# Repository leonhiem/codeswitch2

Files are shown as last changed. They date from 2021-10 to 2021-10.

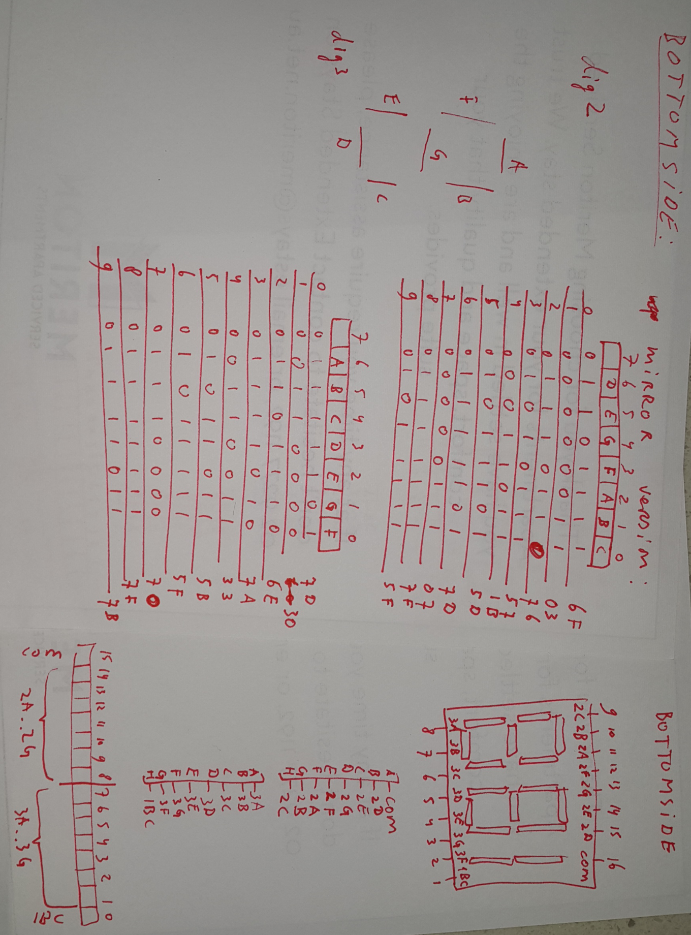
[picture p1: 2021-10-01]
firmware/doc/lcd_bottomside.png

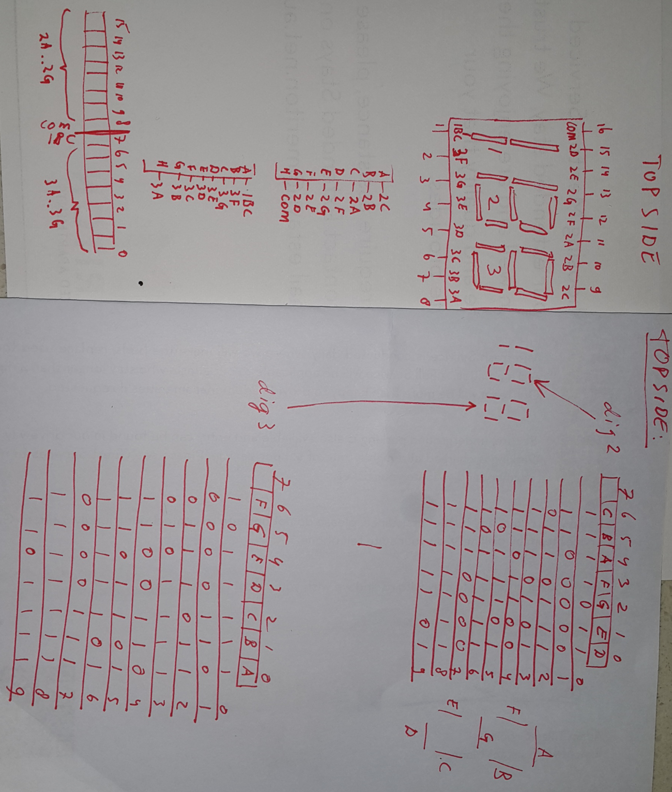
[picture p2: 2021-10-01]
firmware/doc/lcd_topside.png

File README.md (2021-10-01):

# codeswitch2
Codeswitch 2nd edition. To open/close a relay

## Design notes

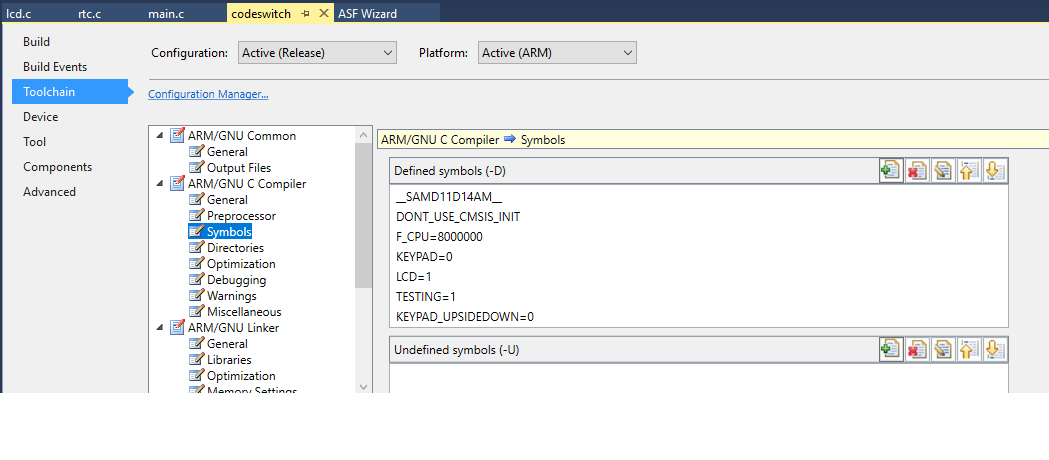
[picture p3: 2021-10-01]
firmware/codeswitch2/samd11/compiler.png

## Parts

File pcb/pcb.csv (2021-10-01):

Reference | Quantity | Value | Footprint | Datasheet | Mfg_code | BOM
C1 C11 | 2 | 10u/25V | capacitor:C_0805_reflow |  | TMK212BBJ106KG-T
C10 C2 C6 C7 C8 C9 | 6 | 100n | capacitor:C_0805_reflow |  | C0805C104K5RACTU
C12 C13 C3 | 3 | 4u7/25V | capacitor:C_0805_reflow |  | CL21A475KAQNNNG
C4 C5 | 2 | 15pF | capacitor:C_0805_reflow |  | CL21C150JBANNNC
D1 D3 | 2 | 1N4148 | Diodes:SOD-80A |  | LL4148
D2 | 1 | S1DB | Diodes_SMD:D_SMB_Handsoldering |  | S1DB-13-F
F2 | 1 | Polyfuse 1.1A-hold 2.2A-trip | Resistors_SMD:R_1812 |  | 0ZCG0110BF2B
J1 | 1 | AUX Ctrl | Pin_Headers:Pin_Header_Straight_1x06_Pitch2.54mm
LCD1 | 1 | LUMEX_LCD_S2X1C50TR | lcd:LUMEX_LCD_S2X1C50TR |  | LCD-S2X1C50TR
LS1 | 1 | piezo | buzzer:MagneticBuzzer_StarMicronics_HMB-06_HMB-12 |  | PT-1340P-PQ
P1 | 1 | serial | Pin_Headers:Pin_Header_Straight_1x04_Pitch2.54mm |  | PRPC004SBAN-M71RC
P3 | 1 | Atmel-ICE | myconnectors:Atmel_ICE |  | 3220-10-0100-00
P2 P4 P5 P6 P7 P9 | 6 | (faston male 6.35mm) | myconnectors:faston_m_63 | http://www.digikey.nl/product-detail/en/te-connectivity-amp-connectors/1217861-1/A100452TR-ND/1148769 | 1217861-1
Q10 Q2 Q5 | 3 | MMBT3906 | TO_SOT_Packages_SMD:SOT-23 |  | MMBT3906LT3G
Q1 Q11 Q12 Q13 Q3 Q4 Q6 Q8 Q9 | 9 | MMBT3904 | TO_SOT_Packages_SMD:SOT-23 |  | MMBT3904LT3G
Q7 | 1 | PSMN7R5-60YLX | TO_SOT_Packages_SMD:TDSON-8-1_HandSoldering |  | PSMN7R5-60YLX
R15 R16 R30 R33 R35 R6 | 6 | 4k7 | resistor:R_0805_reflow |  | RMCF0805FT4K70
R13 R14 R17 R22 R24 R26 R37 R4 R7 | 9 | 100k | resistor:R_0805_reflow |  | RMCF0805FT100K
R1 R11 R19 R2 R25 R29 R38 | 7 | 150 | resistor:R_0805_reflow |  | RMCF0805FT150R
R28 | 1 | 3k | resistor:R_0805_reflow |  | RMCF0805FT3K00
R10 R12 R18 R23 R27 R3 R31 R32 R36 R8 R9 | 11 | 10k | resistor:R_0805_reflow |  | RMCF0805FT10K0
R34 | 1 | 1M | resistor:R_0805_reflow |  | RMCF0805JT1M00
R20 R21 R5 | 3 | 1k | resistor:R_0805_reflow |  | RMCF0805FT1K00
SW1 SW10 SW11 SW12 SW2 SW3 SW4 SW5 SW6 SW7 SW8 SW9 | 12 | button | myconnectors:SW_SPST_keypad
TP1 TP3 TP5 TP6 TP7 TP8 | 6 | TP | Pin_Headers:Pin_Header_Straight_1x01_Pitch2.54mm
TP9 | 1 | GND | Pin_Headers:Pin_Header_Straight_1x01_Pitch2.54mm
U2 | 1 | LM358 | Housings_SOIC:SOIC-8_3.9x4.9mm_Pitch1.27mm |  | LM358ADT
U3 | 1 | ATSAMD11D14A-M | Housings_DFN_QFN:QFN-24-1EP_4x4mm_Pitch0.5mm | http://www.atmel.com/Images/Atmel-42363-SAM-D11_Datasheet.pdf | ATSAMD11D14A-MUT | MCU ATMEL ATSAMD11D14A-M
U4 U5 | 2 | 74HC595 | Housings_SOIC:SOIC-16_3.9x9.9mm_Pitch1.27mm |  | MM74HC595M
U1 U6 | 2 | HT7533 | TO_SOT_Packages_SMD:SOT-89-3_Handsoldering
Y1 | 1 | 32.768kHz | xtal:Crystal_SMD_Abracon_4pin_32768khz |  | ABS25-32.768KHZ-T
ZD1 | 1 | ESDA6V1W5 | TO_SOT_Packages_SMD:SOT-353_SC-70-5_Handsoldering |  | ESDA6V1W5

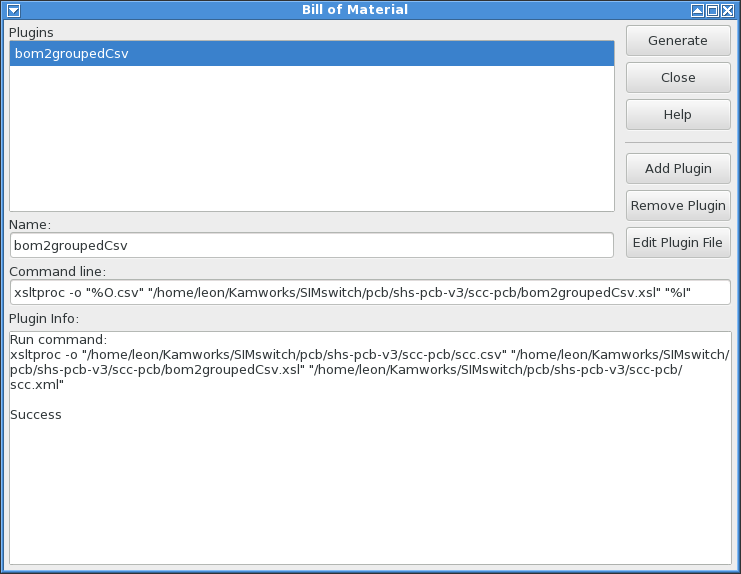
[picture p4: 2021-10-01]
pcb/howto_bom.png

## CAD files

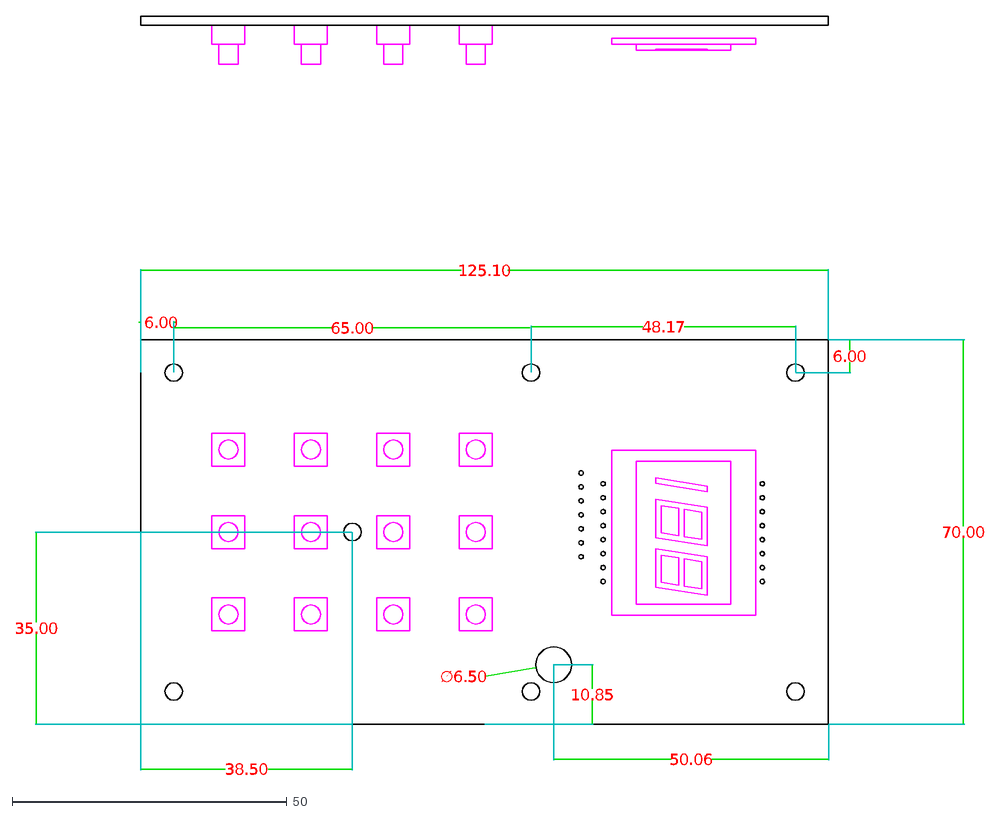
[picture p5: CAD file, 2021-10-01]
pcb/part1-2-NEW.dxf
70.00
125.10
6.00
65.00
48.17
38.50
35.00
10.85
50.06
∅6.50

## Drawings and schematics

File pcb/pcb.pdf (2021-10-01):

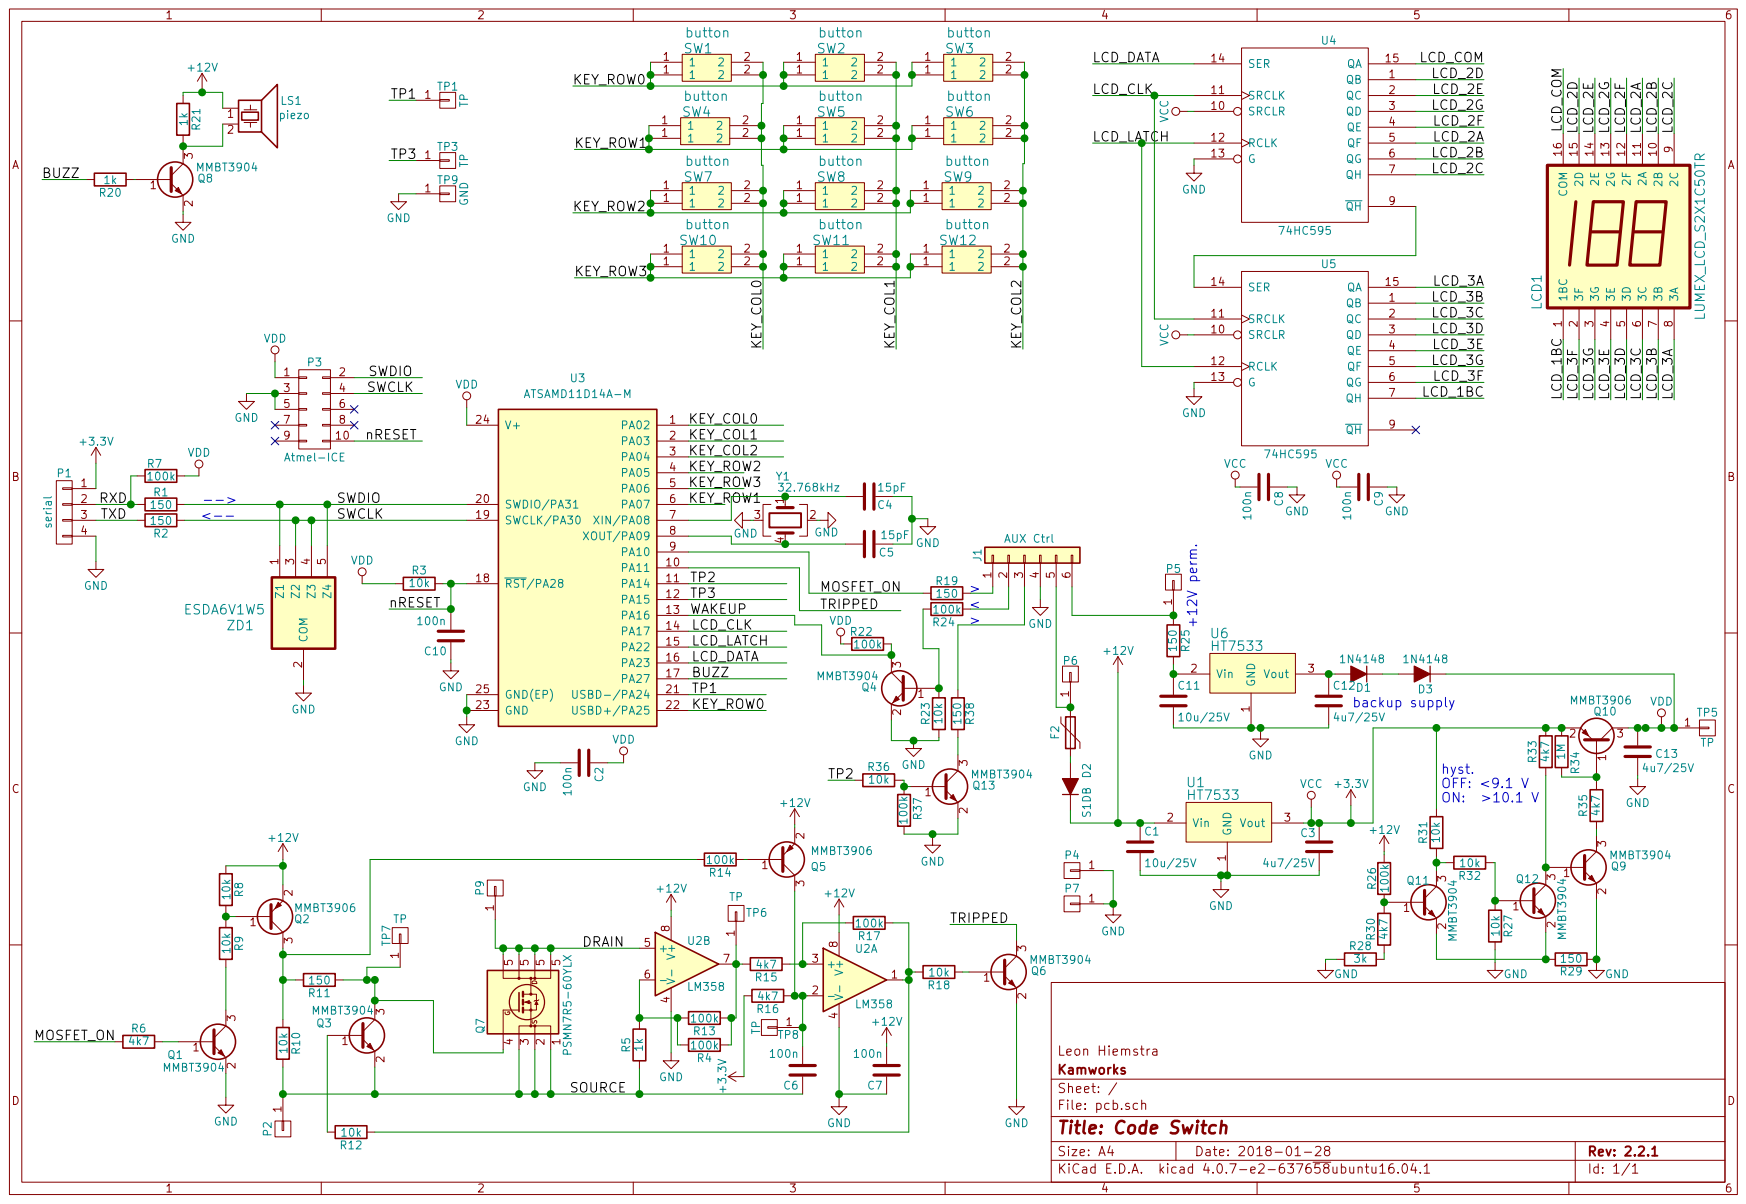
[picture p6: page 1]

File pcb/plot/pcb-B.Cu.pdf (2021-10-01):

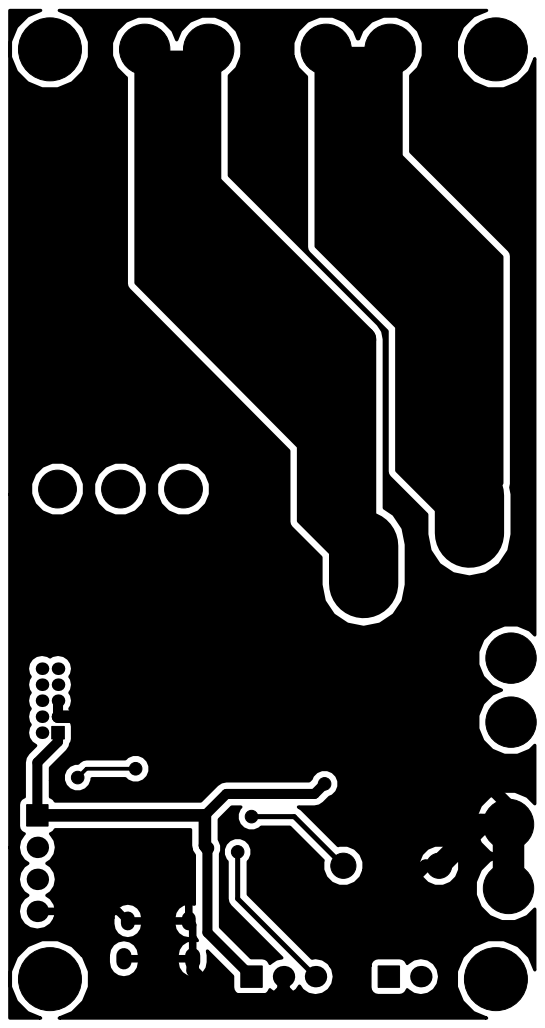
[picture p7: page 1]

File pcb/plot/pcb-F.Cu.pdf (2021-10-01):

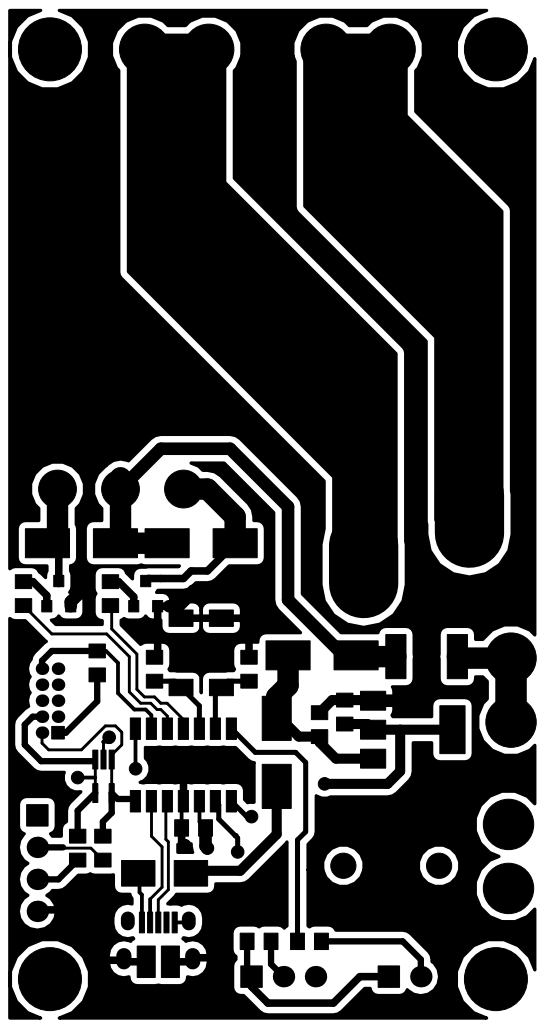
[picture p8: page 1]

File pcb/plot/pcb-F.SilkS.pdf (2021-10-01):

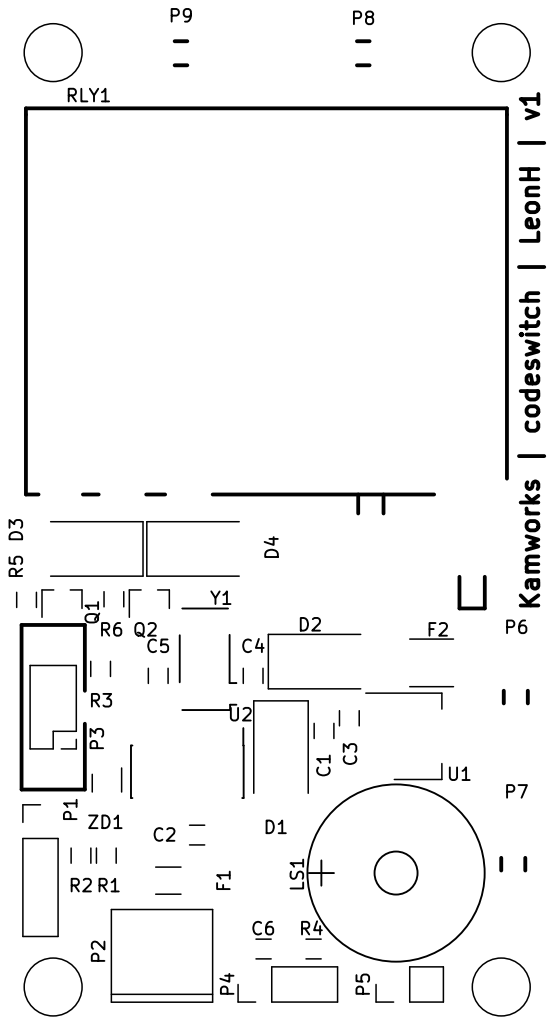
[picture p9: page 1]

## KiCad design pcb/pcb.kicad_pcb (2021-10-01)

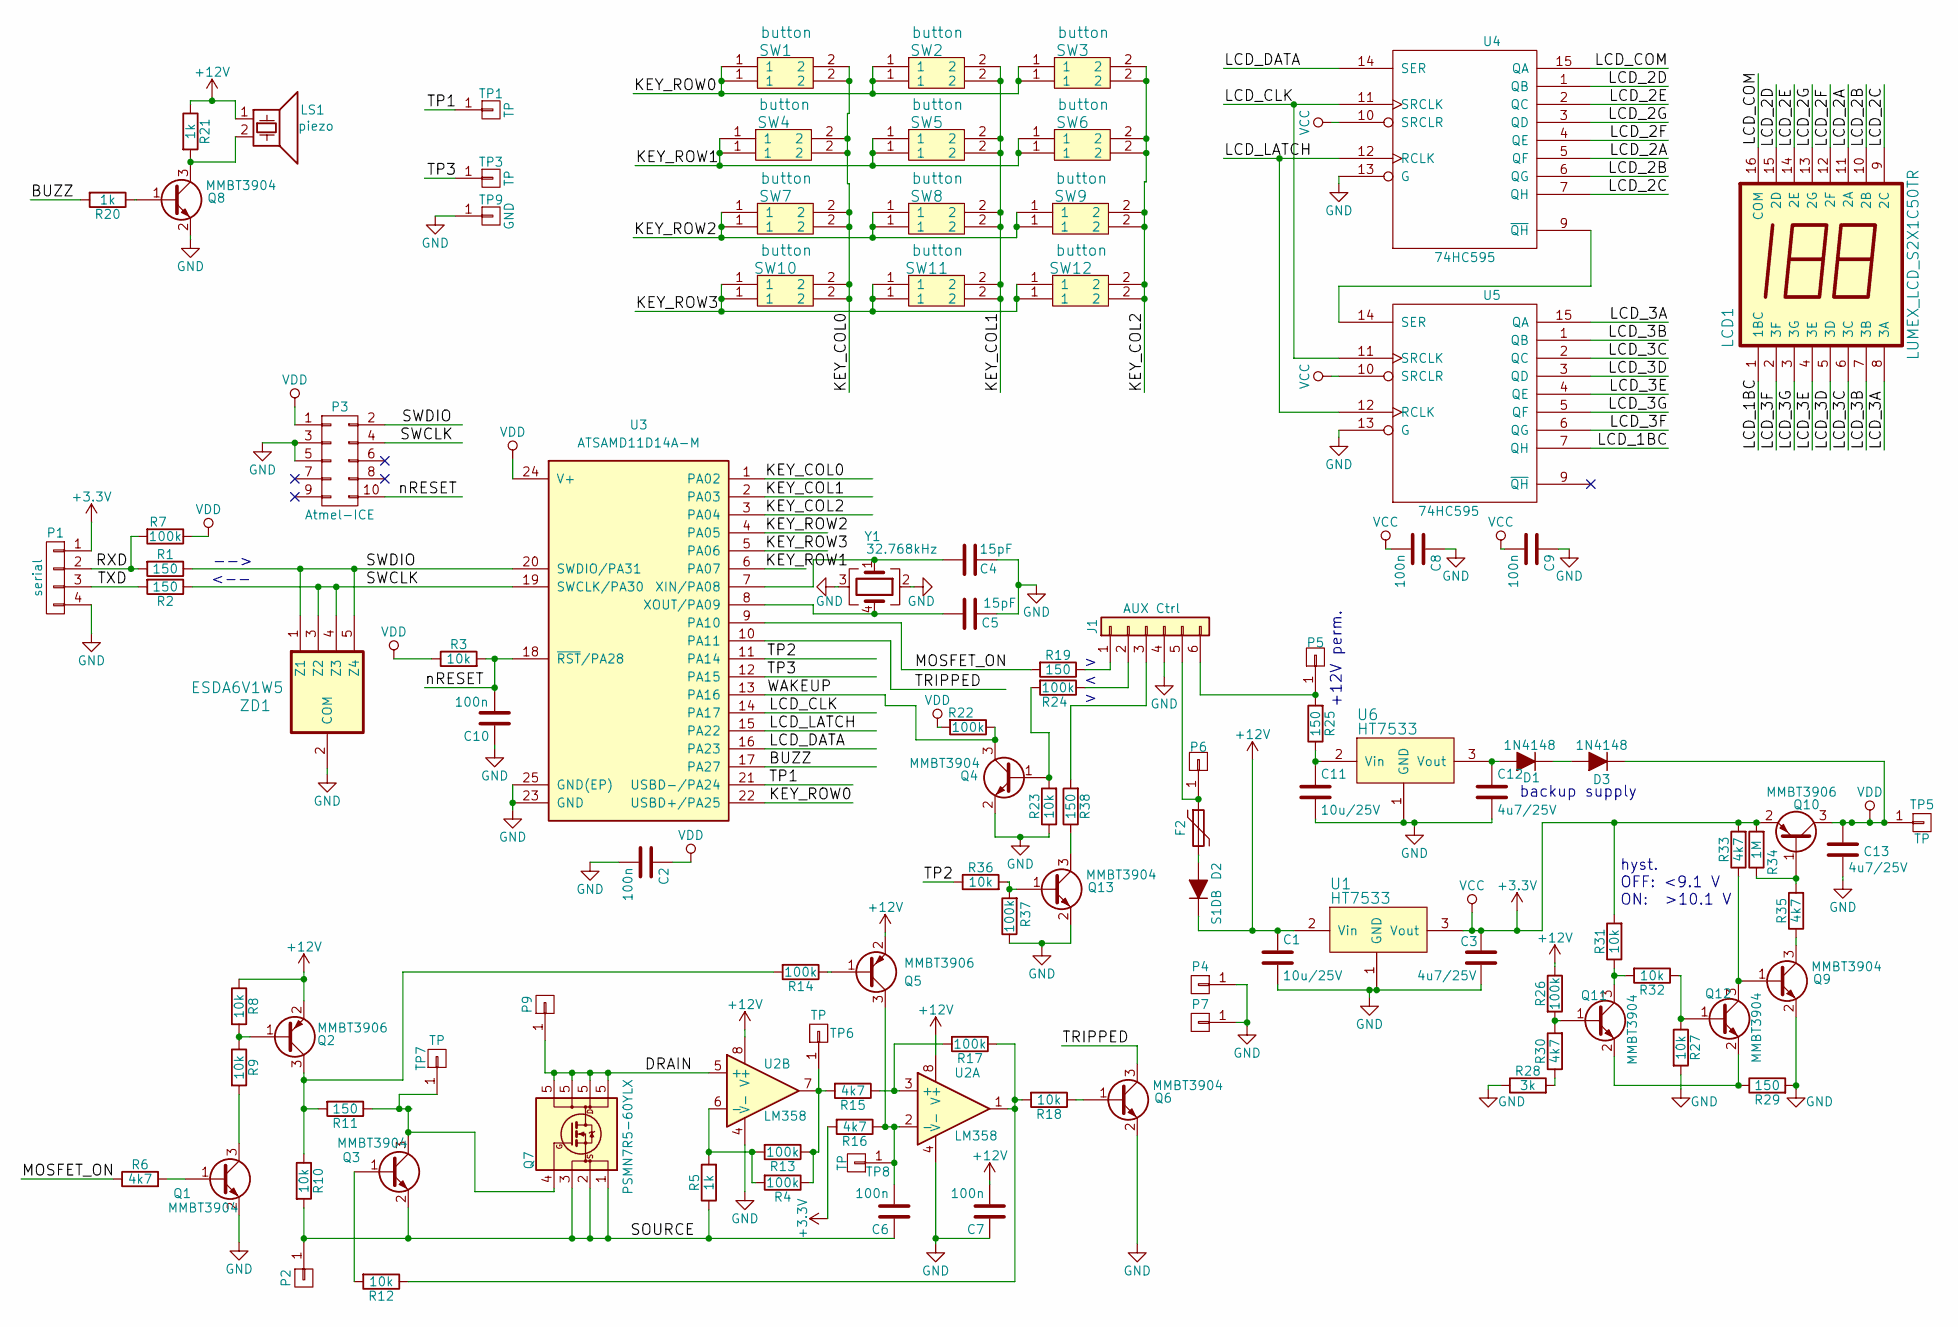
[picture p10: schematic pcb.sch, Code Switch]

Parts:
C1, C11: 10u/25V; C_0805_reflow
C2, C6, C7, C8, C9, C10: 100n; C_0805_reflow
C3, C12, C13: 4u7/25V; C_0805_reflow
C4, C5: 15pF; C_0805_reflow
D1, D3: 1N4148; SOD-80A
D2: S1DB; D_SMB_Handsoldering
F2: Polyfuse 1.1A-hold 2.2A-trip; R_1812
J1: AUX Ctrl; Pin_Header_Straight_1x06_Pitch2.54mm
LCD1: LUMEX_LCD_S2X1C50TR
LS1: piezo; MagneticBuzzer_StarMicronics_HMB-06_HMB-12
P1: serial; Pin_Header_Straight_1x04_Pitch2.54mm
P2, P4, P5, P6, P7, P9: (faston male 6.35mm); faston_m_63
P3: Atmel-ICE; Atmel_ICE
Q1, Q3, Q4, Q6, Q8, Q9, Q11, Q12, Q13: MMBT3904; SOT-23
Q2, Q5, Q10: MMBT3906; SOT-23
Q7: PSMN7R5-60YLX; TDSON-8-1_HandSoldering
R1, R2, R11, R19, R25, R29, R38: 150; R_0805_reflow
R3, R8, R9, R10, R12, R18, R23, R27, R31, R32, R36: 10k; R_0805_reflow
R4, R7, R13, R14, R17, R22, R24, R26, R37: 100k; R_0805_reflow
R5, R20, R21: 1k; R_0805_reflow
R6, R15, R16, R30, R33, R35: 4k7; R_0805_reflow
R28: 3k; R_0805_reflow
R34: 1M; R_0805_reflow
SW1, SW2, SW3, SW4, SW5, SW6, SW7, SW8, SW9, SW10, SW11, SW12: button; SW_SPST_keypad
TP1, TP3, TP5, TP6, TP7, TP8: TP; Pin_Header_Straight_1x01_Pitch2.54mm
TP9: GND; Pin_Header_Straight_1x01_Pitch2.54mm
U1, U6: HT7533; SOT-89-3_Handsoldering
U2: LM358; SOIC-8_3.9x4.9mm_Pitch1.27mm
U3: ATSAMD11D14A-M; QFN-24-1EP_4x4mm_Pitch0.5mm
U4, U5: 74HC595; SOIC-16_3.9x9.9mm_Pitch1.27mm
Y1: 32.768kHz; Crystal_SMD_Abracon_4pin_32768khz
ZD1: ESDA6V1W5; SOT-353_SC-70-5_Handsoldering

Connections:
+3V3: C3.1, C8.2, C9.2, P1.1, Q10.2 (E), R16.2, R31.2, R33.2, R34.2, U1.3 (Vout), U4.10 (SRCLR), U4.16 (VCC), U5.10 (SRCLR), U5.16 (VCC)
+12V: C1.1, C7.2, D2.1 (K), LS1.1, Q2.2 (E), Q5.2 (E), R8.1, R21.1, R26.1, U1.2 (Vin), U2.8 (V+)
/BUZZ: R20.2, U3.17 (PA27)
/DRAIN: P9.1, Q7.5 (D), U2.5 (+)
/KEY_COL0: SW1.2, SW4.2, SW7.2, SW10.2, U3.1 (PA02)
/KEY_COL1: SW2.2, SW5.2, SW8.2, SW11.2, U3.2 (PA03)
/KEY_COL2: SW3.2, SW6.2, SW9.2, SW12.2, U3.3 (PA04)
/KEY_ROW0: SW1.1, SW2.1, SW3.1, U3.22 (USBD+/PA25)
/KEY_ROW1: SW4.1, SW5.1, SW6.1, U3.6 (PA07)
/KEY_ROW2: SW7.1, SW8.1, SW9.1, U3.4 (PA05)
/KEY_ROW3: SW10.1, SW11.1, SW12.1, U3.5 (PA06)
/LCD_1BC: LCD1.1 (1BC), U5.7 (QH)
/LCD_2A: LCD1.11 (2A), U4.5 (QF)
/LCD_2B: LCD1.10 (2B), U4.6 (QG)
/LCD_2C: LCD1.9 (2C), U4.7 (QH)
/LCD_2D: LCD1.15 (2D), U4.1 (QB)
/LCD_2E: LCD1.14 (2E), U4.2 (QC)
/LCD_2F: LCD1.12 (2F), U4.4 (QE)
/LCD_2G: LCD1.13 (2G), U4.3 (QD)
/LCD_3A: LCD1.8 (3A), U5.15 (QA)
/LCD_3B: LCD1.7 (3B), U5.1 (QB)
/LCD_3C: LCD1.6 (3C), U5.2 (QC)
/LCD_3D: LCD1.5 (3D), U5.3 (QD)
/LCD_3E: LCD1.4 (3E), U5.4 (QE)
/LCD_3F: LCD1.2 (3F), U5.6 (QG)
/LCD_3G: LCD1.3 (3G), U5.5 (QF)
/LCD_CLK: U3.14 (PA17), U4.11 (SRCLK), U5.11 (SRCLK)
/LCD_COM: LCD1.16 (COM), U4.15 (QA)
/LCD_DATA: U3.16 (PA23), U4.14 (SER)
/LCD_LATCH: U3.15 (PA22), U4.12 (RCLK), U5.12 (RCLK)
/MOSFET_ON: R6.1, R19.2, U3.9 (PA10)
/RXD: P1.2, R1.2, R7.2
/SOURCE: C6.1, P2.1, Q3.2 (E), Q7.1 (S), Q7.2 (S), Q7.3 (S), R5.1, R10.2
/SWCLK: P3.4, R2.1, U3.19 (SWCLK/PA30), ZD1.3 (Z2), ZD1.4 (Z3)
/SWDIO: P3.2, R1.1, U3.20 (SWDIO/PA31), ZD1.1 (Z1), ZD1.5 (Z4)
/TP1: TP1.1, U3.21 (USBD-/PA24)
/TP2: R36.1, U3.11 (PA14)
/TP3: TP3.1, U3.12 (PA15)
/TRIPPED: Q6.3 (C), U3.10 (PA11)
/TXD: P1.3, R2.2
/WAKEUP: Q4.3 (C), R22.1, U3.13 (PA16)
/nRESET: C10.2, P3.10, R3.2, U3.18 (~RST~/PA28)
GND: C1.2, C2.2, C3.2, C4.1, C5.1, C7.1, C8.1, C9.1, C10.1, C11.2, C12.2, C13.2, J1.4, P1.4, P3.3, P3.5, P4.1, P7.1, Q1.2 (E), Q4.2 (E), Q6.2 (E), Q8.2 (E), Q9.2 (E), Q13.2 (E), R23.1, R27.2, R28.1, R29.2, R37.1, TP9.1, U1.1 (GND), U2.4 (V-), U3.23 (GND), U3.25 (GND(EP)), U4.8 (GND), U4.13 (G), U5.8 (GND), U5.13 (G), U6.1 (GND), Y1.2, Y1.3, ZD1.2 (COM)
unnamed: C4.2, U3.7 (XIN/PA08), Y1.1
unnamed: C5.2, U3.8 (XOUT/PA09), Y1.4
unnamed: C6.2, Q5.3 (C), R16.1, TP8.1, U2.2 (-)
unnamed: C11.1, R25.1, U6.2 (Vin)
unnamed: C12.1, D1.2 (A), U6.3 (Vout)
unnamed: D1.1 (K), D3.2 (A)
unnamed: D2.2 (A), F2.2
unnamed: F2.1, J1.5, P6.1
unnamed: J1.1, R19.1
unnamed: J1.2, R24.1
unnamed: J1.3, R38.2
unnamed: J1.6, P5.1, R25.2
unnamed: LS1.2, Q8.3 (C), R21.2
unnamed: Q1.1 (B), R6.2
unnamed: Q1.3 (C), R9.2
unnamed: Q2.1 (B), R8.2, R9.1
unnamed: Q2.3 (C), R10.1, R11.2, R14.2
unnamed: Q3.1 (B), R12.2
unnamed: Q3.3 (C), Q7.4 (G), R11.1, TP7.1
unnamed: Q4.1 (B), R23.2, R24.2
unnamed: Q5.1 (B), R14.1
unnamed: Q6.1 (B), R18.1
unnamed: Q8.1 (B), R20.1
unnamed: Q9.3 (C), R35.1
unnamed: Q10.1 (B), R34.1, R35.2
unnamed: Q11.1 (B), R26.2, R30.2
unnamed: Q11.2 (E), Q12.2 (E), R29.1
unnamed: Q11.3 (C), R31.1, R32.2
unnamed: Q12.1 (B), R27.1, R32.1
unnamed: Q9.1 (B), Q12.3 (C), R33.1
unnamed: Q13.1 (B), R36.2, R37.2
unnamed: Q13.3 (C), R38.1
unnamed: R12.1, R17.1, R18.2, U2.1
unnamed: R4.1, R13.1, R15.2, TP6.1, U2.7
unnamed: R4.2, R5.2, R13.2, U2.6 (-)
unnamed: R15.1, R17.2, U2.3 (+)
unnamed: R28.2, R30.1
unnamed: U4.9 (~QH), U5.14 (SER)
VDD: C2.1, C13.1, D3.1 (K), P3.1, Q10.3 (C), R3.1, R7.1, R22.2, TP5.1, U3.24 (V+)

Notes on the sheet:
-->
<--
backup supply
+12V perm.
hyst. OFF: <9.1 V ON: >10.1 V

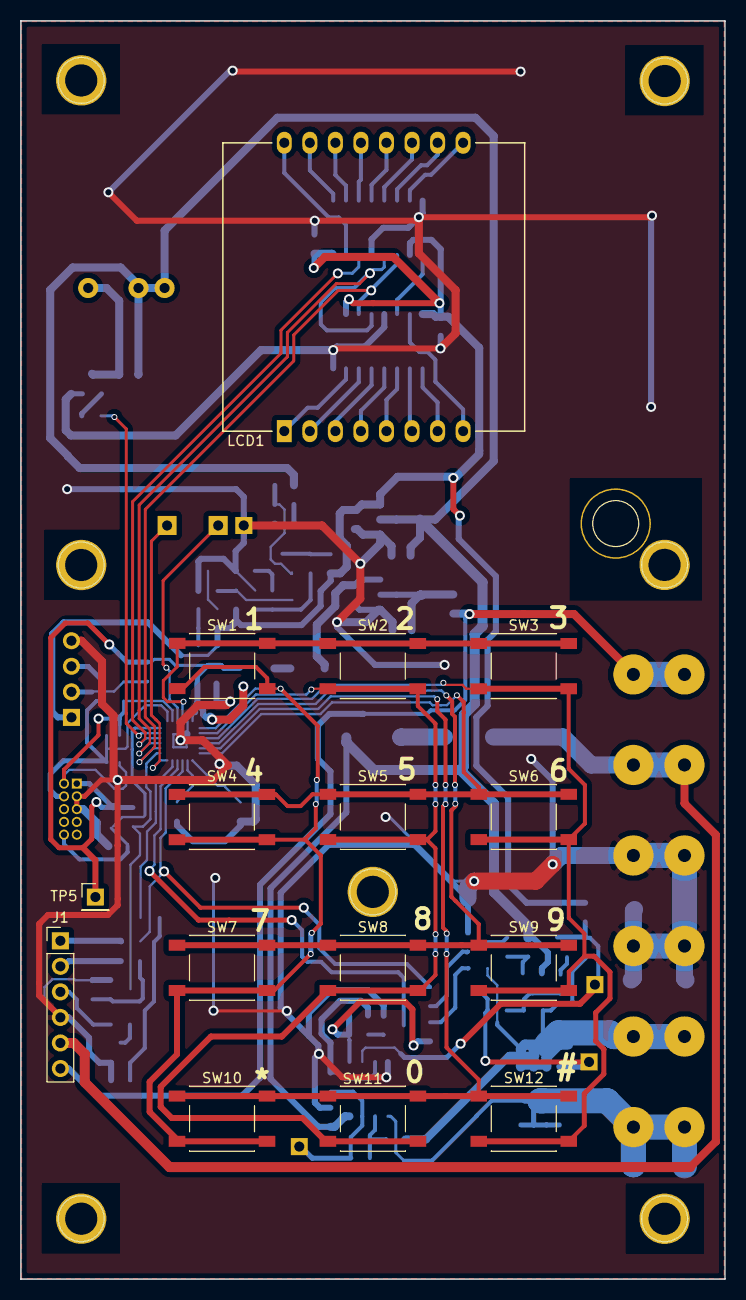
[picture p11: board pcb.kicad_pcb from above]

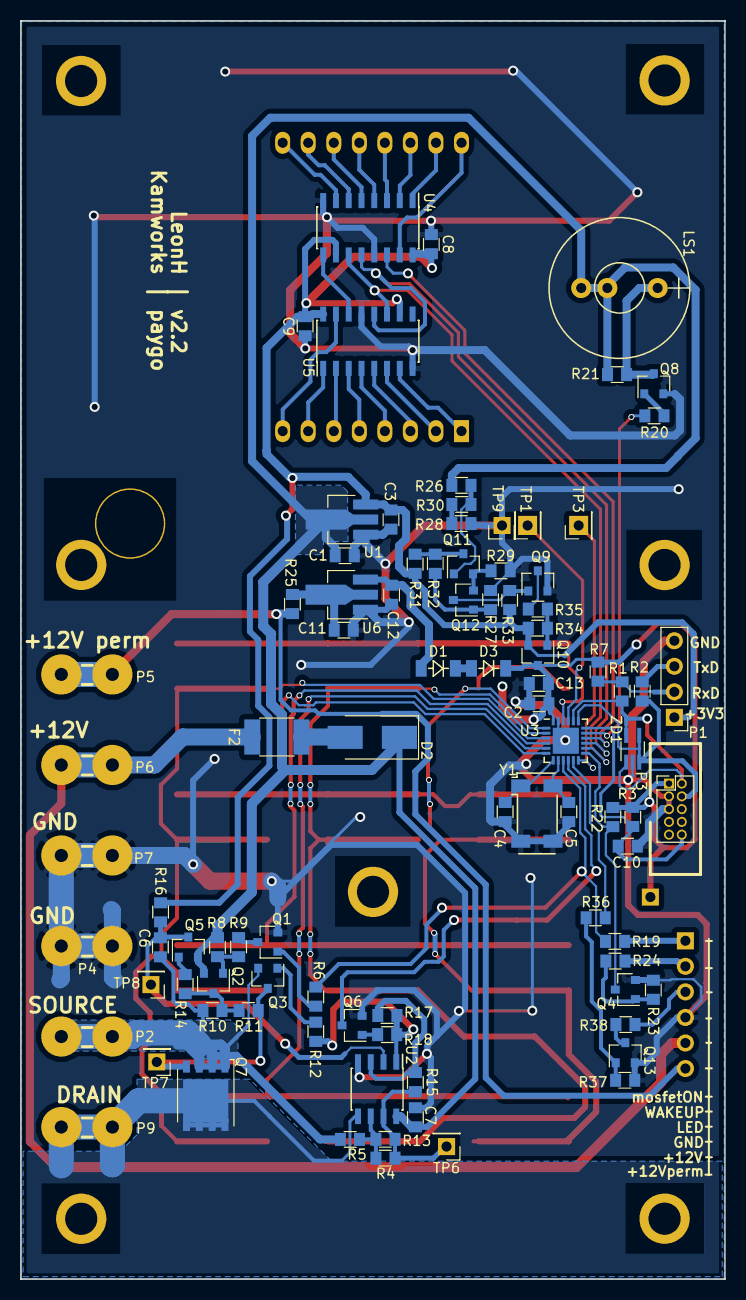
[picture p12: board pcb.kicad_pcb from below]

Board: 2 copper layers, 70.0 x 125.1 mm, 106 parts (91 on the bottom side), 82 nets.

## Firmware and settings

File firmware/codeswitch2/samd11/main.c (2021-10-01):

/*
 * Kamworks Codeswitch2 firmware
 *
 * Author: Leon Hiemstra <l.hiemstra@gmail.com>
 *
 * Compiler tool: Atmel Studio 7.0.1417
 *
 * Microcontroller: ATSAMD11D14AM
 * Required fuse settings: none (keep default)
 *
 * (Arduino IR decoder derived from: ...)
 */

//-----------------------------------------------------------------------------
#include <stdlib.h>
#include <stdio.h>
#include <stdint.h>
#include <stdbool.h>
#include <string.h>
#include "samd11.h"
#include "hal_gpio.h"
#include "utils.h"
#include "rtc.h"
#include "tone.h"
#include "flash.h"
#include "keypad.h"
#include "lcd.h"
#include "wdt.h"


#define VERSION     2
#define SUBVERSION  15


#ifndef KEYPAD_INTEGRATED
#  define KEYPAD_INTEGRATED 1 // enabled
#endif

#ifndef TESTING
#  define TESTING 0 // disabled
#endif

#ifndef LCD
#  define LCD 0  // top (0=bottom)
#endif

volatile bool alarmTriggered = false;

volatile bool usart_rx_ready=false;
volatile bool usart_tx_ready=true;
volatile bool print_info=false;
volatile uint8_t bod33_tripped,wdt_wakeup;
uint8_t rcause;
#define RXBUF_SIZE 100
char rxbuf[RXBUF_SIZE];
int data_receive_idx=0;

volatile unsigned long milliseconds=0UL;
int millis_div20=0;
int millis_div4=0;
static Eeprom eeprom;


void all_init(int8_t onoff);

static void uart_putc(char c)
{
    while (!(SERCOM1->USART.INTFLAG.reg & SERCOM_USART_INTFLAG_DRE));
    SERCOM1->USART.DATA.reg = c;
}
static void uart_puts(char *s)
{   while (*s) uart_putc(*s++); }

static void uart_puts_info(char *s)
{   if(print_info) { while (*s) uart_putc(*s++); } }

//void SYSCTRL_Handler(void)
void irq_handler_sysctrl(void)
{
    if(SYSCTRL->INTFLAG.bit.BOD33DET) {
        bod33_tripped=1;
        SYSCTRL->INTFLAG.reg = SYSCTRL_INTFLAG_BOD33DET; // clear interrupt  
    }    
}

// Errata ref 15513: disable BOD12 before sleep and enable after sleep
void set_bod12(uint8_t onoff)
{
    volatile uint32_t *ptr = (volatile uint32_t *)0x40000838;
    if(onoff) *ptr = 4; else *ptr = 6;
}

static void sys_init(uint8_t onoff)
{
    if(onoff==0) {
        SYSCTRL->OSC8M.bit.PRESC = 0;
       PM->APBAMASK.reg &= ~PM_APBAMASK_GCLK; 
    } else {
    PM->APBAMASK.reg |= PM_APBAMASK_GCLK;
    // Switch to 8MHz clock (disable prescaler)
    SYSCTRL->OSC8M.bit.PRESC = 0;
    SYSCTRL->BOD33.reg = 0; // disable to avoid spurious interrupts
    SYSCTRL->BOD33.reg = SYSCTRL_BOD33_LEVEL(48) | SYSCTRL_BOD33_CEN | SYSCTRL_BOD33_MODE |
                         SYSCTRL_BOD33_RUNSTDBY | SYSCTRL_BOD33_ACTION(2) | SYSCTRL_BOD33_HYST;
                         
    
    
    bod33_tripped=0;
    wdt_wakeup=0;
    SYSCTRL->BOD33.reg |= SYSCTRL_BOD33_ENABLE;
    while((SYSCTRL->PCLKSR.reg & SYSCTRL_PCLKSR_B33SRDY) == 0);
    SYSCTRL->INTENSET.reg = SYSCTRL_INTENSET_BOD33DET;
    NVIC_EnableIRQ(SYSCTRL_IRQn);
    
    // Enable interrupts
    asm volatile ("cpsie i");
    }    
}


void check_bod(void)
{
    uint8_t bod33_trip;
    //uart_puts_info("chk bod\n\r");
    __disable_irq();
    bod33_trip=bod33_tripped;
    bod33_tripped=0;   
    __enable_irq();
    
    // sleep when BOD or wakeup pin = 0
    if(bod33_trip || HAL_GPIO_WAKEUP_PIN_read()==0) {
        uart_puts_info(">>> bod33_trip SLEEP! <<<\n\r");
        all_init(0);
        set_bod12(0);
        
        while(1) {
            wdt_wakeup=0;            
            wdt_sleep(1000);
            
            // in case the wakeup pin is activated:       
            if( ((SYSCTRL->PCLKSR.reg & SYSCTRL_PCLKSR_BOD33DET) == 0) &&
                (HAL_GPIO_WAKEUP_PIN_read() != 0) ) {
                                        
                break;
            }
            
            // in case the alarm is just triggered:
            if( ((SYSCTRL->PCLKSR.reg & SYSCTRL_PCLKSR_BOD33DET) == 0) && alarmTriggered) {
                
                break;
            }
        }       
        set_bod12(1);
        all_init(1);
        uart_puts_info(">>> bod33 ok wakeup <<<\n\r");
    }      
}

//-----------------------------------------------------------------------------
void irq_handler_tc1(void)
{  
  if (TC1->COUNT16.INTFLAG.reg & TC_INTFLAG_MC(1)) {
            
      millis_div20++; 
      if(millis_div20 >= 20) {
            milliseconds++;
            millis_div20=0;
      }      
       millis_div4++;
       if(millis_div4 >= 5) {
           millis_div4=0;           
           lcd_clk(); // 20kHz / 4 = 5kHz
       }
  }
  TC1->COUNT16.INTFLAG.reg = TC_INTFLAG_MC(1); 
}

//-----------------------------------------------------------------------------
static void timer1_init(int8_t onoff)
{
  if(onoff==0) {
      TC1->COUNT16.CTRLA.reg &= ~TC_CTRLA_ENABLE;
      PM->APBCMASK.reg &= ~PM_APBCMASK_TC1;
  } else {
      PM->APBCMASK.reg |= PM_APBCMASK_TC1;
      GCLK->CLKCTRL.reg = GCLK_CLKCTRL_ID(TC1_GCLK_ID) |
                          GCLK_CLKCTRL_CLKEN | GCLK_CLKCTRL_GEN(0);
    
      TC1->COUNT16.CTRLA.reg = TC_CTRLA_MODE_COUNT16 | TC_CTRLA_WAVEGEN_MFRQ |
                               TC_CTRLA_PRESCALER_DIV8 | TC_CTRLA_PRESCSYNC_RESYNC;
    
      TC1->COUNT16.COUNT.reg = 0;
      
        TC1->COUNT16.CC[0].reg = 48; // 20kHz
        TC1->COUNT16.COUNT.reg = 0;
        
      TC1->COUNT16.CTRLA.reg |= TC_CTRLA_ENABLE;
      TC1->COUNT16.INTENSET.reg = TC_INTENSET_MC(1);
      NVIC_EnableIRQ(TC1_IRQn);
  }
}


volatile uint8_t serial_rxbuf;
volatile bool serial_rxflag=false;

void irq_handler_sercom1(void)
{
    uint8_t c;
    if (SERCOM1->USART.INTFLAG.bit.RXC) {
        c = SERCOM1->USART.DATA.bit.DATA;
        serial_rxbuf = c;
        serial_rxflag = true;
    }
}



//-----------------------------------------------------------------------------
static void uart_init(int8_t onoff)
{
  uint32_t baud = 115200;
  uint64_t br = (uint64_t)65536 * (F_CPU - 16 * baud) / F_CPU;

  
  HAL_GPIO_UART_TX_pmuxen(PORT_PMUX_PMUXE_C_Val);
  HAL_GPIO_UART_RX_in();
  HAL_GPIO_UART_RX_pullup();
  HAL_GPIO_UART_RX_pmuxen(PORT_PMUX_PMUXE_C_Val);

  if(onoff==0) {
      SERCOM1->USART.CTRLA.reg &= ~SERCOM_USART_CTRLA_ENABLE;
      PM->APBCMASK.reg &= ~PM_APBCMASK_SERCOM1;
      HAL_GPIO_UART_TX_disable();
  } else {
      HAL_GPIO_UART_TX_out();
      PM->APBCMASK.reg |= PM_APBCMASK_SERCOM1;
    
      GCLK->CLKCTRL.reg = GCLK_CLKCTRL_ID(SERCOM1_GCLK_ID_CORE) |
                          GCLK_CLKCTRL_CLKEN | GCLK_CLKCTRL_GEN(0);
    
      SERCOM1->USART.CTRLA.reg =
          SERCOM_USART_CTRLA_DORD | SERCOM_USART_CTRLA_MODE_USART_INT_CLK |
          SERCOM_USART_CTRLA_RXPO(1/*PAD1*/) | SERCOM_USART_CTRLA_TXPO(0/*PAD0*/);
    
      SERCOM1->USART.CTRLB.reg = SERCOM_USART_CTRLB_RXEN | SERCOM_USART_CTRLB_TXEN |
          SERCOM_USART_CTRLB_CHSIZE(0/*8 bits*/);
    
      SERCOM1->USART.BAUD.reg = (uint16_t)br+1;
      
      // set RX interrupt:
      SERCOM1->USART.INTENSET.reg = SERCOM_USART_INTENSET_RXC;
      
      SERCOM1->USART.CTRLA.reg |= SERCOM_USART_CTRLA_ENABLE;
      NVIC_EnableIRQ(SERCOM1_IRQn);
  }
}

//-----------------------------------------------------------------------------

void print_prompt(void)
{
//    uart_puts("\n\rCMD> ");    
}

char addchar(char c)
{
    char buf[2]={0,0};
    buf[0]=c;
    
    if(buf[0]=='*') {
        data_receive_idx=0;
    } else if(buf[0]=='#' && rxbuf[0]=='*') {
        usart_rx_ready=true;
    } else if(!is_digit(buf[0])) {
        play_song_error();
        //data_receive_idx=0;
        return ' ';
    }
    
    if(data_receive_idx>80) {
        data_receive_idx=0;
        return ' ';
    }
    
//#if (KEYPAD_INTEGRATED==0)
    // possibly lit an LED during a keypress:
    // LED on here
    HAL_GPIO_TP1_set();
 //   HAL_GPIO_TP4_set();
//#endif
    play_toneC();
//#if (KEYPAD_INTEGRATED==0)
    // LED off here
    HAL_GPIO_TP1_clr();
 //   HAL_GPIO_TP4_clr();
//#endif   
    
    strcpy(&rxbuf[data_receive_idx],buf);
    data_receive_idx++;
    return c;
}


void mosfet_switch(bool sw)
{  
  if(sw) { // on
    HAL_GPIO_MOSFET_ON_set();
  } else { // off
    HAL_GPIO_MOSFET_ON_clr();  
  }
}


// returns -1 if passed alarm time already
// returns  >=0 if have still days credit left
int16_t read_print_rtc(bool do_print)
{
    char buf[50];
    Time now,alarm;
    int16_t credit;
    uint8_t show_hours_left=0; // default show days left
    
    getTimeNow(&now);
    getAlarmTimeNow(&alarm);
    
    credit = Days_left(&alarm,&now,show_hours_left,0);
    if(credit<=0) {
        show_hours_left=1;
        credit = Days_left(&alarm,&now,show_hours_left,0);
    }
    if(do_print) {
      sprintf(buf,"\n\r      YY-MM-DD hh:mm\n\r");
      uart_puts_info(buf);
      sprintf(buf," time:%02d-%02d-%02d %02d:%02d\n\r",now.year,now.month,now.day,now.hour,now.minute);
      uart_puts_info(buf);
      sprintf(buf,"alarm:%02d-%02d-%02d %02d:%02d\n\r",alarm.year,alarm.month,alarm.day,alarm.hour,alarm.minute);
      uart_puts_info(buf);
      sprintf(buf,"credit=%d %s left\n\r",credit,(show_hours_left ? "hours" : "days"));
      uart_puts_info(buf);
        
      lcd_write_number_int(credit,show_hours_left);
    }
    if(credit<=0) {
        credit = Days_left(&alarm,&now,0,1); // get credit for minutes left
    }
    return credit;
}
void generate_newalarm(Time *newalarm, Time *now, Time *credit)
{
    Time alarm;
    int16_t oldcredit;
    getAlarmTimeNow(&alarm);
    oldcredit = Days_left(&alarm,now,0,0); // are there days left?    
    if(oldcredit<=0) {
        oldcredit = Days_left(&alarm,now,0,1); // maybe some minutes left?
    }
    
    if(oldcredit < 0) {
        // credit is expired; add credit to now    
        uart_puts_info("add to now\n\r");
        Time_add(newalarm, now, credit);
    } else {
        // credit not yet expired; add credit; move alarm forward
        uart_puts_info("add to alarm\n\r");        
        Time_add(newalarm, &alarm, credit);
    }
}

void code_init(int8_t onoff)
{
  char buf[100];
  
  if(onoff==0) return;
  
  // If this is the first run the "valid" value should be "false"
  if (eeprom.valid == false) {
      mosfet_switch(false);
      uart_puts_info("eeprom empty: mosfet off\n\r");
      setTime(0,0,0);// set time (hour 0-23, minute 0-59, second 0-59)
      setDate(1,1,1);// set date (day 1-31, month 1-12, year 0-99)
      eeprom.seq=99;
      read_print_rtc(true);
      play_song_expired();
 } else {
      int16_t creditleft=-1;
      uart_puts_info("eeprom ok: read values");
      
      // restore time, date, alarm:
      /*
      setTime(eeprom.now.hour,eeprom.now.minute,0);
      setDate(eeprom.now.day,eeprom.now.month,eeprom.now.year);
      setAlarmTime(eeprom.alarm.hour,eeprom.alarm.minute,0);
      setAlarmDate(eeprom.alarm.day,eeprom.alarm.month,eeprom.alarm.year);
      */
      sprintf(buf,"(days=%d) (seq=%d)\n\r",eeprom.days,eeprom.seq);
      uart_puts_info(buf);  
      
      if(eeprom.days==0 && eeprom.minutes==0) {
          uart_puts_info("free mode, no alarm: mosfet on\n\r");
          read_print_rtc(true);
          play_song_success();
          mosfet_switch(true);
      } else {
          creditleft=read_print_rtc(true);
          if(creditleft <= 0) { // passed the alarm time
              uart_puts_info("already expired, mosfet off\n\r");
              play_song_expired(); 
              mosfet_switch(false);                
          } else { // not yet passed the alarm time
              uart_puts_info("enable alarm, mosfet on\n\r");
              enableAlarm(RTC_MODE2_MASK_SEL_YYMMDDHHMMSS_Val);
              play_song_success();
              mosfet_switch(true);
          }
      }
  }
}

uint32_t get_myid(void)
{
    // reserved 30 bits for id.
    // 
    // truncate 128bit id.
        
    // ATSAMD21 replies: 0x67718634504a5230352e3120ff03171c
    // ATSAMD11 replies: 0xe1c74e77514d4b5331202020ff0b4631
        
    // most significant side seems to be more unique.
        
    volatile uint32_t *chip_ptr = (volatile uint32_t *)0x0080A00C; // word0 address
    return (*chip_ptr & 0x3fffffff); // mask 30bits
}
void print_myid(void)
{
    char buf[50];
    uint32_t chipval = get_myid();    
    sprintf(buf, "\n\r%09ld\n\r",chipval);
    uart_puts(buf);
}

void io_init(void)
{
    HAL_GPIO_MOSFET_ON_out();
    HAL_GPIO_MOSFET_ON_clr();
    
    HAL_GPIO_WAKEUP_PIN_in();
    HAL_GPIO_WAKEUP_PIN_pullup();
    
    //HAL_GPIO_LED_RED_out();
    //HAL_GPIO_LED_RED_clr();
#if (KEYPAD_INTEGRATED==0) 
    HAL_GPIO_TP4_disable();      
#endif  
    HAL_GPIO_TP3_disable();    
    HAL_GPIO_TP2_disable();
   
    HAL_GPIO_TP1_out();
    HAL_GPIO_TP1_clr();
}

void show_intro_text(void)
{
  char buf[100];
  sprintf(buf, "Kamworks Codeswitch\n\rVersion=%d.%02d\n\r",VERSION,SUBVERSION);
  uart_puts(buf);
  sprintf(buf, "RCAUSE=0x%x\n\r",rcause);
  uart_puts(buf);
#if (TESTING==1)
  sprintf(buf, "TESTING\n\r"); uart_puts(buf);
  print_info=true;
#endif

  sprintf(buf, "\n\rChipID:"); uart_puts(buf);
  print_myid();
  lcd_write_digits(1, 8, 8, 0); // set test value
  lcd_write_digits(1, 8, 8, 1); // set test value
  lcd_write_digits(1, 8, 8, 2); // set test value
  lcd_write_digits(1, 8, 8, 3); // set test value
  delay_ms(300);
  lcd_write_digits(0, 0xa, 0xa, 0); // reset test value
  lcd_write_digits(0, 0xa, 0xa, 1); // reset test value
  lcd_write_digits(0, 0xa, 0xa, 2); // reset test value
  lcd_write_digits(0, 0xa, 0xa, 3); // reset test value
/*  
  sprintf(buf, "\nHelp: *code#\n\rcode=1: read id\n\rcode=2: remaining days\n\rcode=5: read RTC\n\r");
  uart_puts(buf);
  sprintf(buf, "code=10: info OFF, code=11: info ON\n\r");
  uart_puts(buf);
  sprintf(buf, "code=12: display subversion\n\r");
  uart_puts(buf);
#if (TESTING==1) 
  sprintf(buf, "code=3: mosfet ON\n\rcode=4: mosfet OFF\n\r");
  uart_puts(buf);
  sprintf(buf, "code=5yy: set Year\n\rcode=6mm: set Month\n\rcode=7dd: set Day\n\r");
  uart_puts(buf);
  sprintf(buf, "code=8hh: set Hour\n\rcode=9mm: set Minute\n\r");
  uart_puts(buf);
#endif
  sprintf(buf, "else code is credit (9 or 14 digits)\n\n\r");
  uart_puts(buf);
*/
}

void all_init(int8_t onoff)
{
    bod33_tripped=0;    
    rtc_init(onoff);
    uart_init(onoff);  
    timer1_init(onoff); 
    tone_init(onoff);   
    lcd_init(onoff);
    if(onoff) {
        show_intro_text();
    } 
    code_init(onoff);    
    keypad_init(onoff);
    
    
    /*
    // these ones below seem not differ the low power
    AC->CTRLA.bit.ENABLE = 0; // disable Analog Comperator
    ADC->CTRLA.bit.ENABLE = 0; // disable ADC
    PM->APBCMASK.reg &= ~PM_APBCMASK_AC;
    PM->APBCMASK.reg &= ~PM_APBCMASK_ADC;    
    DAC->CTRLA.bit.ENABLE = 0; // disable DAC
    PM->AHBMASK.bit.USB_ = 0;
    PM->AHBMASK.bit.DMAC_ = 0;
    PM->APBAMASK.bit.EIC_ = 0;
    PM->APBBMASK.bit.USB_ = 0;
    PM->APBBMASK.bit.PORT_ = 0;
    */

    // achieved:
    // 32uA @ 1.8V
    // 68uA @ 3.3V
}
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

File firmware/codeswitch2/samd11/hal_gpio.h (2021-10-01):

/*
 * Copyright (c) 2014-2016, Alex Taradov <alex@taradov.com>
 * All rights reserved.
 *
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
 * THIS SOFTWARE IS PROVIDED BY THE COPYRIGHT HOLDERS AND CONTRIBUTORS "AS IS"
 * AND ANY EXPRESS OR IMPLIED WARRANTIES, INCLUDING, BUT NOT LIMITED TO, THE
 * IMPLIED WARRANTIES OF MERCHANTABILITY AND FITNESS FOR A PARTICULAR PURPOSE
 * ARE DISCLAIMED. IN NO EVENT SHALL THE COPYRIGHT HOLDER OR CONTRIBUTORS BE
 * LIABLE FOR ANY DIRECT, INDIRECT, INCIDENTAL, SPECIAL, EXEMPLARY, OR
 * CONSEQUENTIAL DAMAGES (INCLUDING, BUT NOT LIMITED TO, PROCUREMENT OF
 * SUBSTITUTE GOODS OR SERVICES; LOSS OF USE, DATA, OR PROFITS; OR BUSINESS
 * INTERRUPTION) HOWEVER CAUSED AND ON ANY THEORY OF LIABILITY, WHETHER IN
 * CONTRACT, STRICT LIABILITY, OR TORT (INCLUDING NEGLIGENCE OR OTHERWISE)
 * ARISING IN ANY WAY OUT OF THE USE OF THIS SOFTWARE, EVEN IF ADVISED OF THE
 * POSSIBILITY OF SUCH DAMAGE.
 */

#ifndef _HAL_GPIO_H_
#define _HAL_GPIO_H_

/*- Definitions -------------------------------------------------------------*/
#define HAL_GPIO_PORTA       0
#define HAL_GPIO_PORTB       1
#define HAL_GPIO_PORTC       2

#define HAL_GPIO_PMUX_A      0
#define HAL_GPIO_PMUX_B      1
#define HAL_GPIO_PMUX_C      2
#define HAL_GPIO_PMUX_D      3
#define HAL_GPIO_PMUX_E      4
#define HAL_GPIO_PMUX_F      5
#define HAL_GPIO_PMUX_G      6
#define HAL_GPIO_PMUX_H      7
#define HAL_GPIO_PMUX_I      8

#define HAL_GPIO_PIN(name, port, pin)						\
  static inline void HAL_GPIO_##name##_set(void)				\
  {										\
    PORT->Group[HAL_GPIO_PORT##port].OUTSET.reg = (1 << pin);			\
    (void)HAL_GPIO_##name##_set;						\
  }										\
										\
  static inline void HAL_GPIO_##name##_clr(void)				\
  {										\
    PORT->Group[HAL_GPIO_PORT##port].OUTCLR.reg = (1 << pin);			\
    (void)HAL_GPIO_##name##_clr;						\
  }										\
										\
  static inline void HAL_GPIO_##name##_toggle(void)				\
  {										\
    PORT->Group[HAL_GPIO_PORT##port].OUTTGL.reg = (1 << pin);			\
    (void)HAL_GPIO_##name##_toggle;						\
  }										\
										\
  static inline void HAL_GPIO_##name##_write(int value)				\
  {										\
    if (value)									\
      PORT->Group[HAL_GPIO_PORT##port].OUTSET.reg = (1 << pin);			\
    else									\
      PORT->Group[HAL_GPIO_PORT##port].OUTCLR.reg = (1 << pin);			\
    (void)HAL_GPIO_##name##_write;						\
  }										\
										\
  static inline void HAL_GPIO_##name##_in(void)					\
  {										\
    PORT->Group[HAL_GPIO_PORT##port].DIRCLR.reg = (1 << pin);			\
    PORT->Group[HAL_GPIO_PORT##port].PINCFG[pin].reg |= PORT_PINCFG_INEN;	\
    PORT->Group[HAL_GPIO_PORT##port].PINCFG[pin].reg &= ~PORT_PINCFG_PULLEN;	\
    (void)HAL_GPIO_##name##_in;							\
  }										\
										\
  static inline void HAL_GPIO_##name##_disable(void)					\
  {										\
      PORT->Group[HAL_GPIO_PORT##port].DIRCLR.reg = (1 << pin);			\
      PORT->Group[HAL_GPIO_PORT##port].PINCFG[pin].reg &= ~PORT_PINCFG_INEN;	\
      PORT->Group[HAL_GPIO_PORT##port].PINCFG[pin].reg &= ~PORT_PINCFG_PULLEN;	\
      PORT->Group[HAL_GPIO_PORT##port].PINCFG[pin].reg &= ~PORT_PINCFG_PMUXEN;	\
      (void)HAL_GPIO_##name##_disable;							\
  } \
  \
  static inline void HAL_GPIO_##name##_out(void)				\
  {										\
    PORT->Group[HAL_GPIO_PORT##port].DIRSET.reg = (1 << pin);			\
    PORT->Group[HAL_GPIO_PORT##port].PINCFG[pin].reg |= PORT_PINCFG_INEN;	\
    (void)HAL_GPIO_##name##_out;						\
  }										\
										\
  static inline void HAL_GPIO_##name##_pullup(void)				\
  {										\
    PORT->Group[HAL_GPIO_PORT##port].OUTSET.reg = (1 << pin);			\
    PORT->Group[HAL_GPIO_PORT##port].PINCFG[pin].reg |= PORT_PINCFG_PULLEN;	\
    (void)HAL_GPIO_##name##_pullup;						\
  }										\
										\
  static inline int HAL_GPIO_##name##_read(void)				\
  {										\
    return (PORT->Group[HAL_GPIO_PORT##port].IN.reg & (1 << pin)) != 0;		\
    (void)HAL_GPIO_##name##_read;						\
  }										\
										\
  static inline int HAL_GPIO_##name##_state(void)				\
  {										\
    return (PORT->Group[HAL_GPIO_PORT##port].DIR.reg & (1 << pin)) != 0;	\
    (void)HAL_GPIO_##name##_state;						\
  }										\
										\
  static inline void HAL_GPIO_##name##_pmuxen(int mux)				\
  {										\
    PORT->Group[HAL_GPIO_PORT##port].PINCFG[pin].reg |= PORT_PINCFG_PMUXEN;	\
    if (pin & 1)								\
      PORT->Group[HAL_GPIO_PORT##port].PMUX[pin>>1].bit.PMUXO = mux;		\
    else									\
      PORT->Group[HAL_GPIO_PORT##port].PMUX[pin>>1].bit.PMUXE = mux;		\
    (void)HAL_GPIO_##name##_pmuxen;						\
  }										\
										\
  static inline void HAL_GPIO_##name##_pmuxdis(void)				\
  {										\
    PORT->Group[HAL_GPIO_PORT##port].PINCFG[pin].reg &= ~PORT_PINCFG_PMUXEN;	\
    (void)HAL_GPIO_##name##_pmuxdis;						\
  }										\



HAL_GPIO_PIN(MOSFET_ON,  A, 10)
HAL_GPIO_PIN(UART_TX,   A, 30)
HAL_GPIO_PIN(UART_RX,   A, 31)
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
